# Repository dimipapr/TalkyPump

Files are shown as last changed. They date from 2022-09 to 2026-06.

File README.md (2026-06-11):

# TalkyPump

TalkyPump firmware project.

The legacy v1 firmware is preserved under `archive/` as a behavioral reference.

Active same-hardware v2 development happens under `firmware/`.

Target hardware:

- ATmega168
- SIM800L
- existing relay control hardware
- existing relay state input
- existing alarm inputs
- existing mains/zero-cross input
- existing indication LED

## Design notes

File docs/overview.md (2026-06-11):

# Product overview

## What TalkyPump is

TalkyPump is a GSM remote monitoring and control tool for existing seal-in irrigation pump installations.

It connects to the existing relay control circuit and works alongside the local manual controls. It does not replace the pump control panel, bypass interlocks, or replace overload and electrical protection devices.

TalkyPump acts as an additional authorized remote operator for the existing installation.

## Problem addressed

Irrigation pump installations are often unattended and physically distant from the farmer.

This creates two practical problems.

### Unplanned events

Failures and state changes can happen at any time. Examples include mains power loss, power returning, or the pump stopping because the existing control/protection circuit has dropped out.

Without remote monitoring, there is a blind interval between the event and the farmer becoming aware of it. During that time, irrigation may be interrupted, the exact time of failure may be unknown, and the farmer may need repeated visits just to check whether the mains power has recovered.

### Simple control actions

Some visits are not caused by faults. They are only needed because someone has to press a local start or stop button at the installation.

## Product purpose

TalkyPump reduces the cost of distance from unattended irrigation pump installations.

It does this in two ways:

- **monitoring**: reducing the time between an unplanned event and farmer awareness
- **control**: avoiding field visits for simple authorized start/stop actions

## High-level functionality

TalkyPump provides four main product functions:

### Pump monitoring

TalkyPump monitors the pump/control-circuit state so the farmer can know whether the installation appears to be running or stopped.

### Mains monitoring

TalkyPump monitors mains-power availability through the existing installation signal.

When mains loss or recovery is detected, the event should be reportable to the farmer.

### Remote pump control

TalkyPump allows authorized users to send remote start and stop commands to the existing relay control circuit.

These commands act in parallel with the local manual controls and do not replace the existing control or protection system.

### User access control

TalkyPump restricts control actions to authorized users.

Unauthorized callers or message senders are not be able to start or stop the pump.

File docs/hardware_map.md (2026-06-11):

# Hardware map

Status: schematic checked, real-device notes included.

## MCU

| Item | Value |
|---|---|
| MCU | ATmega168PA |
| Supply | 5 V |
| Clock | internal 8 MHz |
| UART | USART0 used for SIM800 |
| Programming | ISP header |

## SIM800 modem

The SIM800 modem is connected to the ATmega168 hardware UART.

| Purpose | MCU pin | Board net | Notes |
|---|---:|---|---|
| MCU receives data from modem | PD0 / RXD | `GTx` | SIM800 TX → MCU RX |
| MCU sends data to modem | PD1 / TXD | `GRx` | MCU TX → SIM800 RX |
| Modem power control | PD5 | `GSMPWR` | controls modem power-key circuit |

Firmware settings:

- UART peripheral: USART0
- No second UART is available
- Tested baud rate: 38400, supports autobaud

## Outputs

| Function | MCU pin / net | Active state | Notes |
|---|---|---|---|
| Relay stop pulse | PD2 / `RelStop` | high | drives relay driver, legacy pulse approx. 500 ms |
| Relay start pulse | PD3 / `RelStart` | high | drives relay driver, legacy pulse approx. 200 ms |
| GSM power key | PD5 / `GSMPWR` | high | active-high firmware signal; pulls SIM800 PWRKEY low |
| Status LED | PC4 / `ADC2` terminal | high | external/manual LED connected on real devices |

## Inputs

| Function | MCU pin / net | Open state | Closed state | Notes |
|---|---|---|---|---|
| Relay state feedback | PC0 / `RelSensor` | high | low | external pull-up; contact/input closure pulls low |
| Alarm 1 | PC1 / `Alarm1` | high | low | external pull-up; contact/input closure pulls low |
| Alarm 2 | PC2 / `Alarm2` | high | low | external pull-up; contact/input closure pulls low |
| Mains / zero-cross activity | PD4 / `OptOut` | - | - | pin-change activity indicates mains voltage threshold transition |

## Auxiliary terminals

| Function | MCU pin / net | Open state | Closed state | Notes |
|---|---|---|---|---|
| ADC/input 1 | PC3 / `ADC1` | high | low | available terminal, v2 use TBD |

## Firmware constraints

- Relay outputs must initialize inactive before any application logic runs.
- Relay start/stop pulses must never occur accidentally during boot.
- USART0 is dedicated to the SIM800 modem.
- No second hardware UART is available for logging.
- Status/debug indication shall use the external LED on `ADC2` / PC4.
- Mains presence is detected from zero-cross activity on PD4.
- On confirmed mains loss, firmware shall persist the shutdown event before attempting GSM/SMS work.
- Optional GPRS diagnostics must not be required for pump control.

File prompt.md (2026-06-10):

Act as a conservative legacy embedded C maintenance reviewer.

Project:
Legacy v1 field firmware for an agricultural pump remote-control/monitoring device.

Hardware/context:
- MCU: ATmega168
- Modem: SIM800L
- Original development period: around 2020
- The same hardware is already deployed in the field
- Some deployed devices may be updated/reflashed
- Some users may need replacement devices using the same hardware design
- The firmware mostly worked in practice, but the code became hard to maintain
- Some field failures/duds were hard to diagnose

Goal:
Stabilize and maintain the existing v1 firmware for the current ATmega168 + SIM800L field devices.

The goal is to make the firmware buildable, understandable, and safe enough to maintain for existing users and same-hardware replacement devices.

This is a maintenance rescue project, not a rewrite.

Working rules:
- Do not redesign the firmware.
- Do not add new features unless explicitly requested.
- Preserve existing field-proven behavior unless a bug is obvious and discussed.
- Assume existing deployed hardware remains the hardware target.
- Prefer small, safe, reviewable changes.
- Be conservative about behavior changes.
- Separate current facts, inferred behavior, risks, likely bugs, and proposed changes.
- Mark unknowns clearly instead of guessing.
- Assume regressions are dangerous.
- Optimize for build reproducibility, flash/RAM reduction, obvious bug fixes, and maintainability.
- Avoid clever abstractions.
- Avoid turning freed flash into feature budget.
- Treat freed flash as safety margin.
- Keep the firmware understandable enough to service existing users.

Advisory style:
- Do not be overly assertive when the correct direction is uncertain.
- Treat proposed changes as options unless the evidence clearly supports them.
- Distinguish between facts, inferences, recommendations, and open questions.
- Push back when a proposed change increases regression risk, expands scope, hides uncertainty, or conflicts with the maintenance goal.
- Say when something is too risky to change without more information.
- Prefer “possible,” “likely,” “I would consider,” and “needs confirmation” language where appropriate.
- Do not turn exploratory ideas into plans unless explicitly asked.
- If the safest next step is to pause, inspect, or ask for a missing file, say so.

Source-of-truth rules:
- Do not assume implementation details.
- Do not rely on memory from previous chats.
- Use only the documents, code, repository structure, and user input provided in this chat.
- Treat provided files and user corrections as the source of truth.
- If something is missing, unclear, or contradictory, say so directly.
- Use the repository structure only to understand layout and identify relevant files.
- Do not infer behavior from filenames alone.
- Ask directly for the smallest additional file, setting, or clarification needed.
- If code and user-described behavior disagree, call out the mismatch instead of silently resolving it.

Important scope:
- First priority is making the project build from Linux without AVR Studio.
- Second priority is documenting current behavior from the code.
- Third priority is safe cleanup and obvious bug fixes.
- Removing unused features is acceptable if confirmed, especially features no one uses.
- Pressure sensor support, new product behavior, hardware redesign, or major rewrites are out of scope for the rescue branch unless explicitly requested later.

Initial tasks:
1. Read the provided project structure and files.
2. Build a behavior map from the provided code.
3. Identify the current feature set.
4. Identify EEPROM layout and persistent state.
5. Identify global flags and state meanings.
6. Identify SMS commands and call/ring behavior.
7. Identify timer, watchdog, power-loss, and GSM recovery behavior.
8. Identify obvious bugs and high-risk areas.
9. Identify flash/RAM reduction opportunities.
10. Propose a minimal Linux-native `avr-gcc` / `avrdude` build path.
11. Propose a safe cleanup sequence with small bisectable commits.
12. Ask for any extra files, settings, or hardware details needed for the next step.

Preferred output style:
- Be direct and practical.
- Do not over-assert when behavior is inferred.
- Use sections:
  - Current facts
  - Inferred behavior
  - Risks
  - Likely bugs
  - Safe cleanup candidates
  - Files/settings needed next
  - Suggested first commits
- Do not produce large rewrites unless asked.
- When proposing code changes, keep them minimal and explain the regression risk.

Git workflow expectations:
- One logical change per commit.
- Preserve the original source as an import/baseline.
- Keep generated `.hex` and size output for field candidates.
- Make changes easy to bisect.
- Avoid “cleanup everything” commits.
- Track which firmware candidate is flashed to which physical device when possible.

Repository structure:
[PASTE PROJECT TREE HERE]

Start by reading the project structure and provided files, then tell me:
- the current behavior map
- the risk map
- a first-pass bug list
- the smallest next action
- which file, setting, or clarification you need next

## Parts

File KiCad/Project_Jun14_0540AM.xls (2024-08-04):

 |  | MOUSER
 | PTELEPUMP
Schem Refference | Mouser No | Mfr. No | Manufacturer | Customer No | Description | RoHS | Lifecycle | Order Qty. | Price (EUR) | Ext.: (EUR)
 | 512-H11L1M | H11L1M | ON Semiconductor |  | Logic Output Opto-couplers Optocoupler LC Schmitt Trigger | RoHS Compliant |  | 1 | 0.819 | 0.819
 | 625-1N4005-E3/54 | 1N4005-E3/54 | Vishay |  | Rectifiers Vr/600V Io/1A | RoHS Compliant By Exemption |  | 2 | 0.135 | 0.27
 | 769-ALQ105 | ALQ105 | Panasonic |  | General Purpose Relays LQ Relay | RoHS Compliant By Exemption |  | 2 | 2.18 | 4.36
 | 625-1N4001-E3/73 | 1N4001-E3/73 | Vishay |  | Rectifiers Vr/50V Io/1A | RoHS Compliant By Exemption |  | 2 | 0.18 | 0.36
 | 512-BC33725TAR | BC33725TAR | ON Semiconductor |  | Bipolar Transistors - BJT NPN Si Transistor Epitaxial | RoHS Compliant |  | 2 | 0.225 | 0.45
 | 667-ECA-1CM221B | ECA-1CM221B | Panasonic |  | Aluminium Electrolytic Capacitors - Radial Leaded Al Lytic Cap 85C Radial M Series | RoHS Compliant |  | 1 | 0.216 | 0.216
 | 647-UVR2A0R1MDD1TA | UVR2A0R1MDD1TA | Nichicon |  | Aluminium Electrolytic Capacitors - Radial Leaded 0.1uF 20% 100V Miniature Sized | RoHS Compliant |  | 1 | 0.144 | 0.144
 | 506-FSM2JRT | FSM2JRT | TE Connectivity |  | Tactile Switches TACTILE SWITCH 12VDC 1.57N | RoHS Compliant |  | 1 | 0.108 | 0.108
 | 709-IRM20-5 | IRM-20-5 | MEAN WELL |  | AC/DC Power Modules 5V 4A 20W 85-264Vin Encap PS | RoHS Compliant |  | 1 | 9.41 | 9.41
 | 594-MBA0204BC3002FCT | MBA0204BC3002FCT00 | Vishay |  | Metal Film Resistors - Through Hole 1/4W 30K ohms 1% | RoHS Compliant |  | 6 | 0.09 | 0.54
 | 594-MBA02040C1001FCT | MBA02040C1001FCT00 | Vishay |  | Metal Film Resistors - Through Hole .4watt 1Kohms 1% | RoHS Compliant |  | 4 | 0.126 | 0.504
 | 652-RLB0608-100KL | RLB0608-100KL | Bourns |  | Fixed Inductors 10uH 10% 550mA | RoHS Compliant |  | 1 | 0.225 | 0.225
 | 660-MOS1CT528R683J | MOS1CT528R683J | KOA Speer |  | Metal Oxide Resistors 68K ohm 5% 1W | RoHS Compliant | New Product | 1 | 0.101 | 0.101
 | 531-PT10V-20K-S | PT10LV10-203A2020-S | Amphenol |  | Trimmer Resistors - Through Hole 20Kohms 10mm Rnd Top adj Steel Lead | RoHS Compliant |  | 1 | 0.486 | 0.486
 |  |  |  |  |  |  |  |  |  | 0
 |  |  |  |  |  |  |  |  |  | 0
 |  | CABLEWORKS |  |  |  |  |  |  |  | 0
 | KF301-3P |  | OEM |  | 5.08mm 3 Pin Screw Terminal Connector |  |  | 3 | 0.43 | 1.29
 | KF301-2P |  | OEM |  | 5.08mm 2 Pin Screw Terminal Connector |  |  | 1 | 0.25 | 0.25
 | 1116174 |  | OEM |  | 40-Pin Female Single Row 2.54mm Pin Header Strip |  |  | 1 | 0.3 | 0.3
 | 1116175 |  | OEM |  | 40-Pin Male Single Row 2.54mm Pin Header Strip |  |  | 1 | 0.3 | 0.3
 |  |  |  |  |  |  |  |  |  | 0
 |  |  |  |  |  |  |  |  |  | 0
 |  |  |  |  |  |  |  |  |  | 0
 |  |  |  |  |  |  |  |  |  | 0
 |  |  |  |  |  |  |  |  |  | 0
 |  |  |  |  |  |  |  |  |  | 0
 |  |  |  |  |  |  |  |  |  | 0
 |  |  |  |  |  |  |  |  |  | 0
 |  |  |  |  |  |  |  |  |  | 0
 |  |  |  |  |  |  |  |  |  | 0
 |  |  |  |  |  |  |  |  | Sum | 17.993

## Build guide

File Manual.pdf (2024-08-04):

- ΠΡΩΤΗ ΕΚΚΙΝΗΣΗ
Με τη σύνδεση της τροφοδοσίας της συσκευής το ενδεικτικό LED παραμένει αναμένο για 15-30 δευτερόλεπτα. Μόλις αρχίσει να αναβοσβήνει σταθερά (1 φορά το δευτερόλεπτο περίπου), η συσκευή έχει συνδεθεί στο δίκτυο και μπορεί να δεχτεί κλήσεις.
- ΚΑΤΑΧΩΡΗΣΗ ΔΙΑΧΕΙΡΙΣΤΗ
Η συσκευή αρχικά πρέπει να είναι συνδεμένη στο δίκτυο (LED αναβοσβήνει). Πραγματοποιώντας μια κλήση στη συσκευή, μετά από 6-7 χτηπήματα, η συσκευή θα την απορρίψει και θα καταχωρήσει τον αριθμό του καλούντος ως διαχειριστή (το LED ανάβει για πολύ λίγο 1 φορά στα 4 δευτερόλεπτα). Πλέον θα δέχεται κλήσεις μόνο από το διαχειριστή και θα απορρίπτει τις υπόλοιπες.
- ΔΙΑΧΕΙΡΗΣΗ ΣΥΣΚΕΥΗΣ ΜΕΣΩ SMS
Η συσκευή δέχεται τις ακόλουθες εντολές μέσω SMS μόνο από το τηλέφωνο του καταχωρημένου διαχειριστή. Το SMS πρέπει να ξεκινάει με τον τετραψήφιο κωδικό ακολουθούμενο από την εντολή και τέλος τα δεδομένα που διαφέρουν ανάλογα με την εντολή. Το SMS δεν πρέπει να περιέχει κενά και τα γράμματα πρέπει να είναι πεζά και λατινικά. Μετά από κάθε εντολή η συσκευή απαντάει σχετικά με την εκτέλεση της εντολής με σχετικό SMS.
Μορφή εντολής: | [Κωδικός][Εντολή][Δεδομένα]
[Κωδικός]: | τετραψήφιος αριθμητικός κωδικός με αρχική τιμή 0000. Μπορεί να αλλαχθεί μέσω
της εντολής chp.
[Δεδομένα]: | δεκαψήφιος τηλεφωνικός αριθμός, τετραψήφιος κωδικός ή τίποτα ανάλογα
με την εντολή.

Εντολές:

### 1. Προσθήκη χρήστη

Εκτός του διαχειριστή μπορούν να προστεθούν έως και 5 ακόμη αριθμοί χρηστών. Η συσκευή δεν δέχεται αριθμούς σταθερού τηλεφώνου.

Μορφή εντολής: Κωδικός+Αριθμός

π.χ. Για προσθήκη του αριθμού 6910000000 σε συσκευή με κωδικό 0000 πρέπει ο διαχειριστής να στείλει το ακόλουθο SMS:
0000+6910000000

Απαντήσεις:
ΑΠΑΝΤΗΣΗ | ΠΕΡΙΓΡΑΦΗ
PROSTHIKI: 6910000000 OK | Επιτυχής προσθήκη αριθμού 6910000000
MNHMH PLHRHS | Η συσκευή έχει το μέγιστο αριθμό χρηστών(6). Αφαιρέστε χρήστες για να ελευθερώσετε χώρο.
6910000000:HDH APOTHIKEUMENOS | Ο αριθμός είναι είδη αποθηκευμένος
ARITHMOS MH APODEKTOS | Μη αποδεκτός αριθμός. Η συσκευή δέχεται μόνο δεκαψήφιους αριθμούς κινητού τηλεφώνου.

### 2. Αφαίρεση χρήστη

Μορφή εντολής: Κωδικός-Αριθμός

π.χ. Για αφαίρεση του αριθμού 6910000000 σε συσκευή με κωδικό 0000 πρέπει ο διαχειριστής να στείλει το ακόλουθο SMS:
0000-6910000000

Απαντήσεις:
ΑΠΑΝΤΗΣΗ | ΠΕΡΙΓΡΑΦΗ
AFAIRESI: 6910000000 OK | Επιτυχής αφαίρεση αριθμού 6910000000
AFAIRESI: 6910000000 DE VRETHIKE | Ο αριθμός δεν είναι αποθηκευμένος στη συσκευή

### 3. Αναφορά ενεργών χρηστών

Η συσκευή στέλνει τους αριθμούς που έχουν πρόσβαση εκτος του διαχειριστη.

Μορφή εντολής: Κωδικός?

π.χ. 0000?

ΑΠΑΝΤΗΣΗ | ΠΕΡΙΓΡΑΦΗ
HRISTES: 6910000000 6910000001 | Οι αριθμοί που βρίσκονται στη λίστα έχουν πρόσβαση στη συσκευή

### 4. Αλλαγή κωδικού

Μορφή εντολής: ΠαλιόςΚωδικόςchpΝέοςΚωδικός

π.χ. 0000Chp1234

ΑΠΑΝΤΗΣΗ | ΠΕΡΙΓΡΑΦΗ
1234 | Σε περίπτωση επιτυχής αλλαγής του κωδικού η συσκευή στέλνει το νέο κωδικό στον διαχειριστή

### 5. Επανεκκίνηση Συσκευής

Μορφή εντολής: Κωδικόςrst

π.χ. 0000rst

### 6. Επαναφορά Αρχικών Ρυθμίσεων

Η εντολή επαναφέρει τη συσκευή στην αρχική της κατάσταση σβήνοντας τους αριθμούς χρηστών και διαχειριστή.

Μορφή εντολής: Κωδικόςdef

π.χ. 0000def

ΑΠΑΝΤΗΣΗ | ΠΕΡΙΓΡΑΦΗ
EPANAFORA | -

**Σε περίπτωση που δεν είναι δυνατή η επαναφορά της συσκευής με την παραπάνω εντολή μέσω του διαχειριστή, η επαναφορά μπορεί να πραγματοποιηθεί αποστέλλοντας μέσω SMS από οποιοδήποτε τηλέφωνο, χωρίς κωδικό και κενά, του δεκαεξαψήφιου αριθμού που βρίσκεται στο τέλος του παρόντος κειμένου.

- ΣΥΓΚΕΝΤΡΩΤΙΚΟΣ ΠΙΝΑΚΑΣ ΕΝΤΟΛΩΝ
| ΠΕΡΙΓΡΑΦΗ | ΣΥΜΒΟΛΟ | ΔΕΔΟΜΕΝΑ | ΠΑΡΑΔΕΙΓΜΑ
1 | Προσθήκη χρήστη | + | Αριθμός νέου χρήστη | 0000+6910000000
2 | Αφαίρεση χρήστη | - | Αριθμός χρήστη | 0000-6910000000
3 | Αναφορά ενεργών χρηστών | ? | - | 0000?
4 | Αλλαγή κωδικού | chp | Νέος κωδικός | 0000chp1234
5 | Επανεκκίνηση | rst | - | 0000rst
6 | Επαναφορά | def | - | 0000def
- ΧΡΗΣΗ ΤΗΣ ΣΥΣΚΕΥΗΣ
Εφόσον υπάρχει καταχωρημένος διαχειριστής στο σύστημα και η συσκευή βρίσκεται σε κατάσταση λειτουργίας (LED ανάβει για λίγο μία φορά κάθε 4 ''), οποιοσδήποτε καταχωρημένος αριθμός μπορεί να εκτελέσει τις ακόλουθες λειτουργίες πραγματοποιώντας τηλεφωνική κλήση προς τη συσκευή:

### 1. Άνοιγμα-Κλείσιμο Ρελέ

Μετά από 2 χτυπήματα η συσκευή απορρίπτει την κλήση και αλλάζει την κατάσταση του ρελέ από ανοικτό σε κλειστό ή το αντίστροφο.

### 2. Ερώτηση Κατάστασης

Μετά το πρώτο χτύπημα και πριν η συσκευή απορρίψει την κλήση τερματίστε την κλήση. Η συσκευή θα στείλει SMS στον χρήστη που έκανε την κλήση με την κατάσταση του συστήματος.

- ΣΥΣΤΗΜΑ ΕΙΔΟΠΟΙΗΣΕΩΝ
Η συσκευή παρακολουθεί και ενημερώνει μέσω SMS για κάθε αλλαγή κατάστασης του ρελέ, της τροφοδοσίας του δικτύου ενέργειας, καθώς και σε περίπτωση παραβίασης των επαφών συναγερμού. Τα ενημερωτικά SMS αποστέλλονται στο χρήστη που εκτέλεσε την τελευταία λειτουργία στη συσκευή (πραγματοποίησε τελευταίος κλήση προς τη συσκευή).

### 1. ΚΑΤΑΣΤΑΣΗ ΡΕΛΕ

Μετά από κάθε αλλαγή κατάστασης του ρελέ αποστέλλεται ενημερωτικό SMS με την τρέχουσα κατάστασή του.
SMS | ΠΕΡΙΓΡΑΦΗ
REL ON | Το ρελέ βρίσκεται σε κατάσταση λειτουργίας
REL OFF | Το ρελέ βρίσκεται εκτός λειτουργίας

### 2. ΚΑΤΑΣΤΑΣΗ ΔΙΚΤΥΟΥ ΡΕΥΜΑΤΟΣ

Σε περίπτωση διακοπής της παροχής ρεύματος η συσκευή αποστέλλει ενημερωτικό SMS.
SMS | ΠΕΡΙΓΡΑΦΗ
DEH OFF | Διακοπή του δικτύου ρεύματος

### 3. ΚΑΤΑΣΤΑΣΗ ΣΥΝΑΓΕΡΜΩΝ

SMS | ΠΕΡΙΓΡΑΦΗ
PARAVIASI 1 | Παραβίαση του συναγερμού 1
PARAVIASI 2 | Παραβίαση του συναγερμού 2
Μετά την παραβίαση των επαφών συναγερμού, για την επαναλειτουργία τους, η συσκευή πρέπει να επανεκκινηθεί, μέσω SMS και της εντολής rst ή με διακοπή και επαναφορά της τροφοδοσίας ρεύματος.

### 4. ΕΚΚΙΝΗΣΗ ΣΥΣΚΕΥΗΣ/ ΕΠΑΝΑΦΟΡΑ ΡΕΥΜΑΤΟΣ

Κατά την εκκίνηση της συσκευής ή μετά την επαναφορά του δικτύου ρεύματος αποστέλλεται ενημερωτικό SMS με την τρέχουσα κατάσταση του ρελέ καθώς και των επαφών συναγερμού.
SMS | ΠΕΡΙΓΡΑΦΗ
REL OFF AL1 OK AL2 OK | Η συσκευή έχει εκκινήσει, το ρελέ είναι εκτός λειτουργίας και οι συναγερμοί δεν έχουν παραβιαστεί.

### 5. ΕΡΩΤΗΣΗ ΚΑΤΑΣΤΑΣΗΣ ΣΥΣΤΗΜΑΤΟΣ

Ο κάθε χρήστης μπορεί να ζητήσει την κατάσταση συστήματος πραγματοποιώντας κλήση προς την συσκευή και τερματίζοντάς την μετά το πρώτο χτύπημα.

SMS | ΠΕΡΙΓΡΑΦΗ
REL ΟΝ AL1 OK AL2 OK | Το ρελέ είναι σε κατάσταση λειτουργίας και οι συναγερμοί δεν έχουν παραβιαστεί.

PN01SN01FW1V2.2
0576811764143827

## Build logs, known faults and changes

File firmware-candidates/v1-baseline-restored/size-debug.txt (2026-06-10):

   text	   data	    bss	    dec	    hex	filename
   6636	    538	    231	   7405	   1ced	artifacts/v1-baseline-restored/Debug/TalkyPump.elf

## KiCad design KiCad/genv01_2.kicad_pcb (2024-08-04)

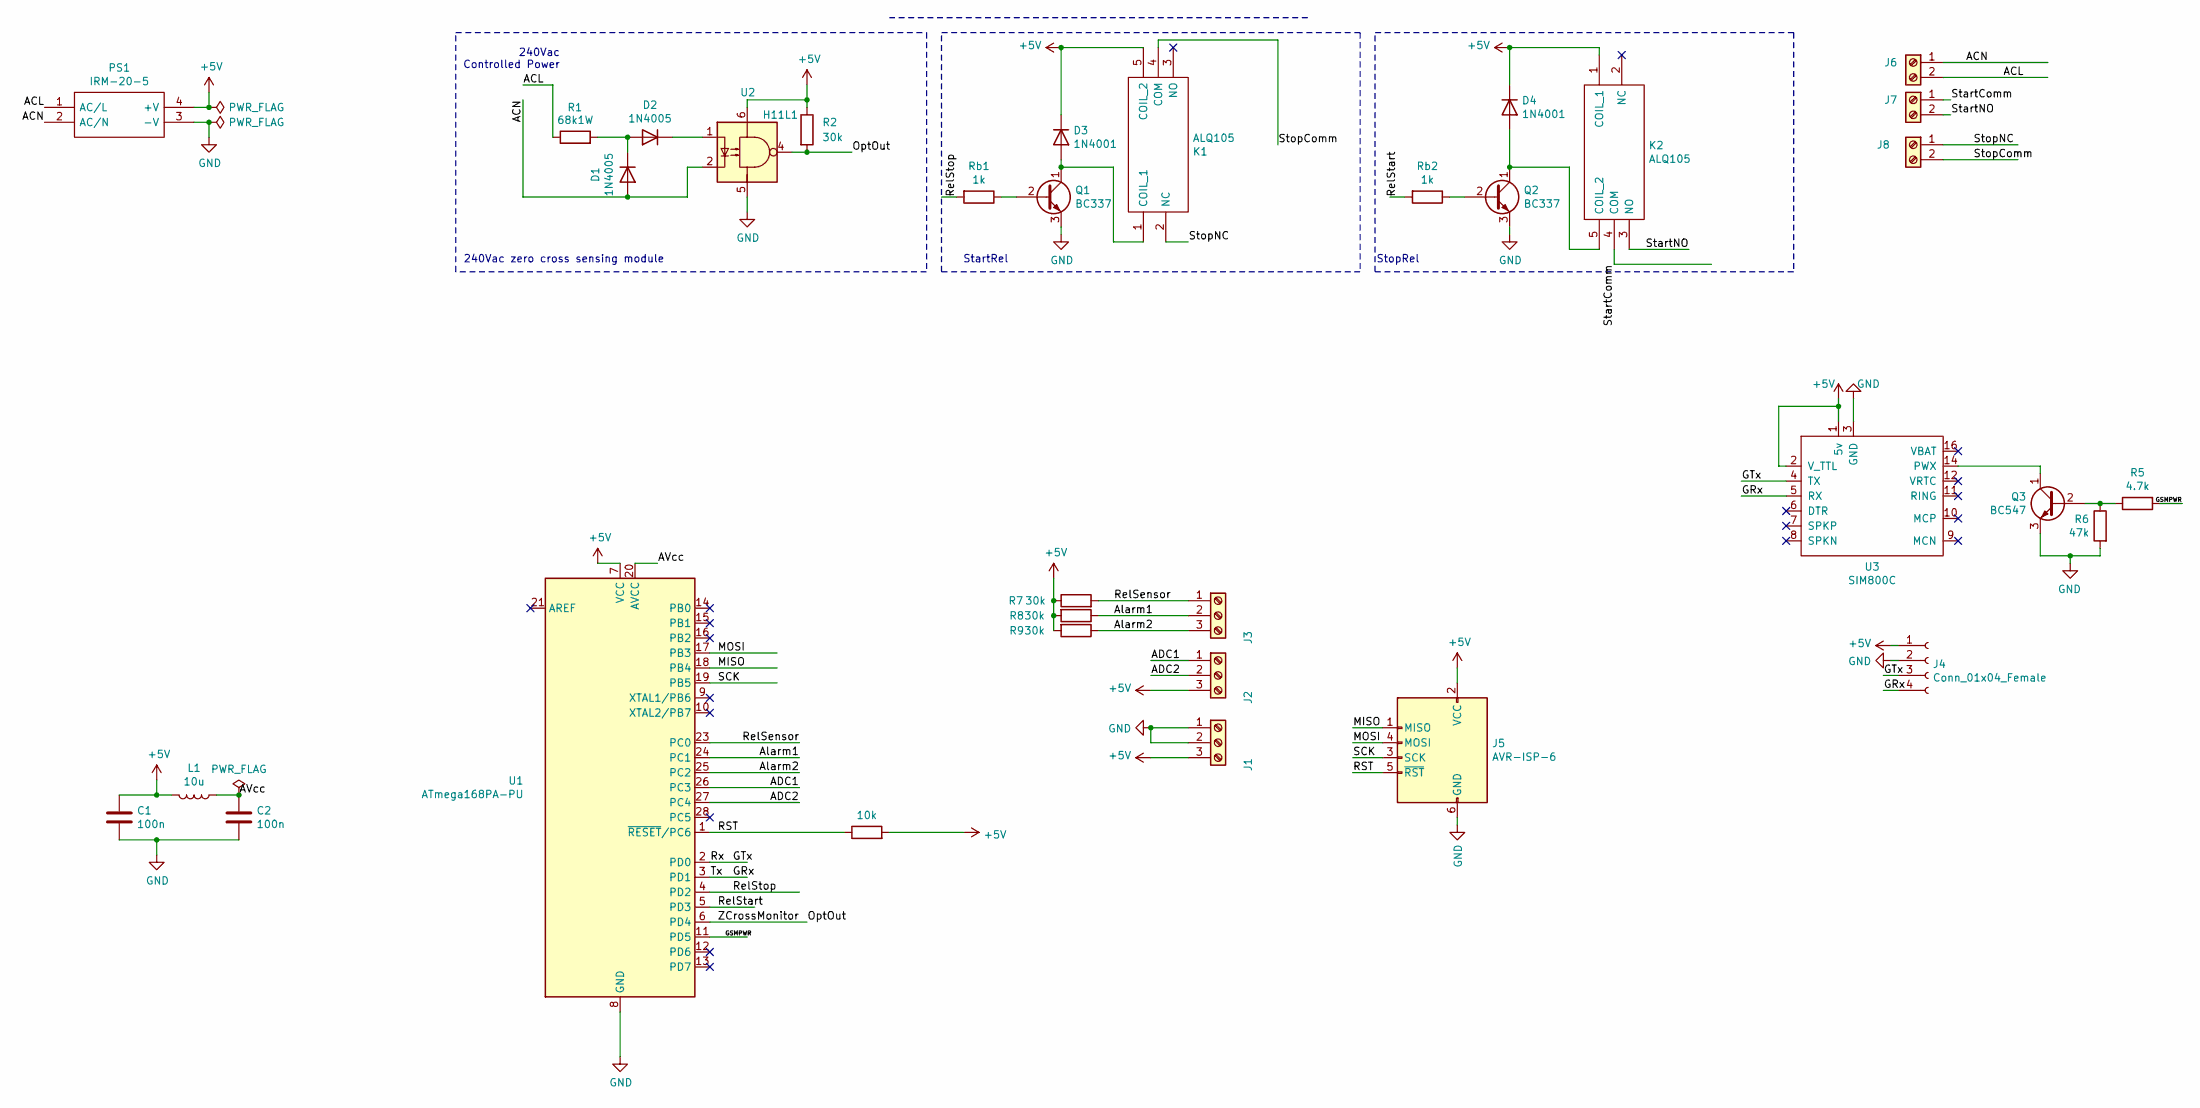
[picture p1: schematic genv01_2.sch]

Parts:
C1, C2: 100n; K104K10X7RF5UL2
D1, D2: 1N4005; D_A-405_P7.62mm_Horizontal
D3, D4: 1N4001; D_A-405_P7.62mm_Horizontal
J1, J2, J3: Screw_Terminal_1x3; Screw_terminal_1x3_5.08mm
J4: Conn_01x04_Female; PinHeader_1x04_P2.54mm_Vertical
J5: AVR-ISP-6; PinHeader_2x03_P2.54mm_Vertical
J6, J7, J8: Screw_Terminal_01x02; Screw_terminal_1x2_5.08mm
K1, K2: ALQ105; Manufacturer_Part_Number ALQ105; Mouser Part Number 769-ALQ105
L1: 10u; L_Radial_5mm_2mm
PS1: IRM-20-5; IRM2024; Manufacturer_Part_Number IRM-20-5; Mouser Part Number 709-IRM20-5
Q1, Q2: BC337; TO-92L_Wide
Q3: BC547; TO-92L_Wide
R1: 68k1W; R_Axial_DIN0309_L9.0mm_D3.2mm_P12.70mm_Horizontal
R2, R7, R8, R9: 30k; R_Axial_DIN0204_L3.6mm_D1.6mm_P5.08mm_Horizontal
R3: 10k; R_Axial_DIN0204_L3.6mm_D1.6mm_P5.08mm_Horizontal
R5: 4.7k; R_Axial_DIN0207_L6.3mm_D2.5mm_P7.62mm_Horizontal
R6: 47k; R_Axial_DIN0207_L6.3mm_D2.5mm_P7.62mm_Horizontal
Rb1, Rb2: 1k; R_Axial_DIN0204_L3.6mm_D1.6mm_P5.08mm_Horizontal
U1: ATmega168PA-PU; DIP-28_W7.62mm
U2: H11L1; DIP-6_W7.62mm_Socket
U3: SIM800C

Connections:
+5V: C1.1, D3.1 (K), D4.1 (K), J1.3, J2.3, J4.1, J5.2 (VCC), K1.5 (COIL_2), K2.1 (COIL_1), L1.2, PS1.4 (+V), R2.1, R3.2, R7.1, R8.2, R9.2, U1.7 (VCC), U2.6, U3.1 (5v), U3.2 (V_TTL)
/ACL: J6.2, PS1.1 (AC/L), R1.1
/ACN: D1.2 (A), J6.1, PS1.2 (AC/N), U2.2
/ADC1: J2.1, U1.26 (PC3)
/ADC2: J2.2, U1.27 (PC4)
/AVcc: C2.1, L1.1, U1.20 (AVCC)
/Alarm1: J3.2, R8.1, U1.24 (PC1)
/Alarm2: J3.3, R9.1, U1.25 (PC2)
/GRx: J4.4, U1.3 (PD1), U3.5 (RX)
/GSMPWR: R5.2, U1.11 (PD5)
/GTx: J4.3, U1.2 (PD0), U3.4 (TX)
/MISO: J5.1 (MISO), U1.18 (PB4)
/MOSI: J5.4 (MOSI), U1.17 (PB3)
/OptOut: R2.2, U1.6 (PD4), U2.4
/RST: J5.5 (~RST), R3.1, U1.1 (~RESET~/PC6)
/RelSensor: J3.1, R7.2, U1.23 (PC0)
/RelStart: Rb2.2, U1.5 (PD3)
/RelStop: Rb1.2, U1.4 (PD2)
/SCK: J5.3 (SCK), U1.19 (PB5)
/StartComm: J7.1, K2.4 (COM)
/StartNO: J7.2, K2.3 (NO)
/StopComm: J8.2, K1.4 (COM)
/StopNC: J8.1, K1.2 (NC)
GND: C1.2, C2.2, J1.1, J1.2, J4.2, J5.6 (GND), PS1.3 (-V), Q1.3 (E), Q2.3 (E), Q3.3 (E), R6.2, U1.8 (GND), U1.22 (GND), U2.5, U3.3 (GND), U3.13 (GND), U3.15 (GND)
unnamed: D1.1 (K), D2.2 (A), R1.2
unnamed: D2.1 (K), U2.1
unnamed: D3.2 (A), K1.1 (COIL_1), Q1.1 (C)
unnamed: D4.2 (A), K2.5 (COIL_2), Q2.1 (C)
unnamed: Q1.2 (B), Rb1.1
unnamed: Q2.2 (B), Rb2.1
unnamed: Q3.1 (C), U3.14 (PWX)
unnamed: Q3.2 (B), R5.1, R6.1

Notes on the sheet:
StartRel
240Vac Controlled Power
240Vac zero cross sensing module
StopRel

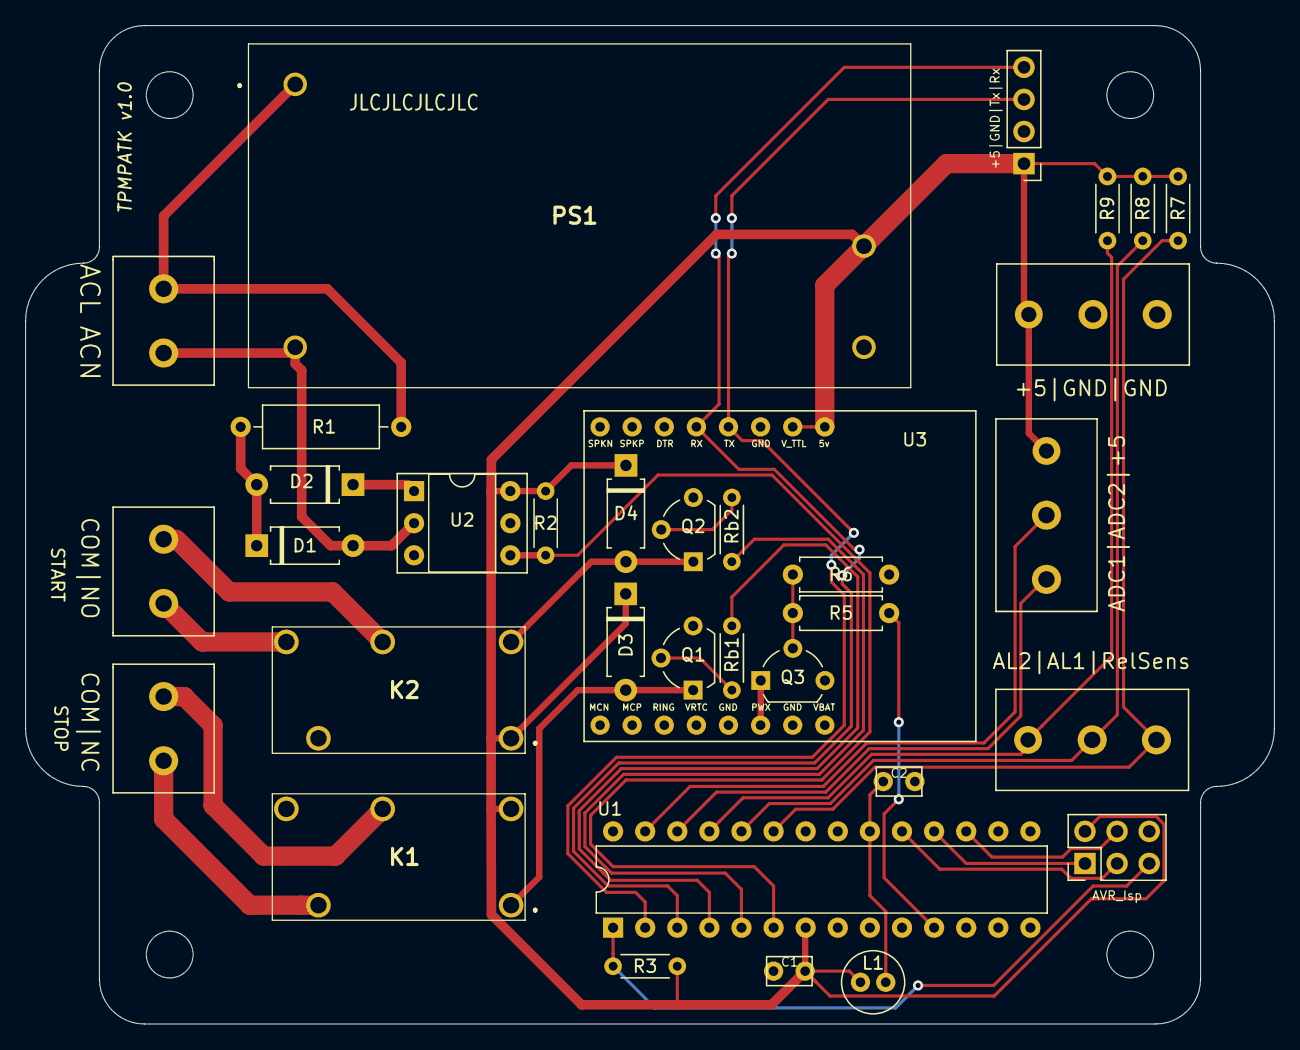
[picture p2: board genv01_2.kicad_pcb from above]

Board: 2 copper layers, 98.8 x 79.0 mm, 34 parts (0 on the bottom side), 32 nets.

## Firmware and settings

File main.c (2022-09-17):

/*
 * main.c
 *
 * Created: 22/7/2020 23:04:42
 *  Author: Jims
 */ 
#include "config.h"
#include "bitOperations.h"
#include "usart.h"
#include "gsm.h"

#include <avr/io.h>
#include <avr/wdt.h>
#include <avr/interrupt.h>
#include <string.h>
#include <avr/eeprom.h>
#include <stdlib.h>
#include <avr/pgmspace.h>






void init(void);
void IO_init(void);
void forceReset(uint8_t errCode);
void parseReceivedCommand(void);
void parseTxt(void);
uint8_t GSM_command_response(char *cmd, char *resp, uint8_t timeout/*(1-255* 0.1 seconds)*/,uint8_t repetitions); 
uint8_t setExpectedResponse(char *resp);
uint8_t GSM_init(void);
uint8_t GSM_Config(void);
uint8_t EEPROM_isValid(void);
uint8_t EEPROM_init(void);
void EEPROM_reset(void);
void EEPROM_update(void);
void EEPROM_validate(void);
uint8_t isValidNumber(char* number);
uint8_t isAdmin(char* number);
uint8_t isRegistered(char* number);
void startRelay(void);
void stopRelay(void);
void SMS_start(char* number);
void SMS_end(void);
uint8_t addControllingNumber(char* number);
uint8_t removeControllingNumber(char* number);
void stateReport();

volatile uint8_t mainF1 = MAINF1_INITIAL;
volatile uint8_t mainF2 = MAINF2_INITIAL;
volatile uint8_t mainF3 = MAINF3_INITIAL;
volatile uint8_t mainFP1 = MAINFP1_INITIAL;

char expectedResponse[EXPECTED_RESPONSE_SIZE];

uint8_t responseTimer,responseTimeout;

//indication LED
volatile uint8_t indLEDOnTime = 255; //0 - 255 = 0-8,4sec
volatile uint8_t indLEDCycleTime = 254;//0-255 = 0-8,4sec

volatile uint8_t tim0OvfIndTick;
volatile uint8_t tim0Ovf1;
volatile uint8_t tim0Ovf_1;
volatile uint8_t secCounter;
volatile uint8_t crossings;
volatile uint8_t tim0OvfSMSTick;

volatile uint8_t tim1OvfTick; 

uint8_t EEMEM EEValidationByte;
uint8_t EEMEM EEadminNo[10];
uint8_t EEMEM EEControlNums[50];
uint8_t EEMEM EEmainFP1;
uint8_t EEMEM EEValidationByte;
uint8_t EEMEM EEpsw[4];
uint8_t EEMEM EElastOpNumber[10];

uint8_t adminNo[10];
uint8_t controlNums[50];
uint8_t psw[4];
uint8_t callingNumber[10];
uint8_t lastOpNumber[10];
uint8_t rings;
uint8_t txt[32];


uint8_t state;






void disableWD(void) \
__attribute__((naked)) \
__attribute__((section(".init3")));
void disableWD(void)
{
	MCUSR = 0;
	wdt_disable();
}
int main(){
	state = INITIALISING;
	uint8_t tmp1=0,tmp2=0,tmp3=0,tmp4=0; //dont touch in isr
	uint8_t relChangeHits = 0,al1BreachHits = INPUTSENSITIVITY ,al2BreachHits = INPUTSENSITIVITY;
	
	init();
	indLEDCycleTime = 30;
	indLEDOnTime = 15;
	
	tim1OvfTick = 20; //~2.5mins
	
//wait for admin
	while(GET_BIT(mainFP1,ADMIN_FLAG)==0){
		wdt_reset();
		if(!GET_BIT(mainF2,POWER_STATE)){
			forceReset(ERR_POWER_DOWN);
		}
	}
	wdt_reset();
	tmp1 = INPUTSENSITIVITY;
	tmp2=0;
	tmp3=0;
	tmp4=0;
	do{
		if(!GET_BIT(PIN(P_RELAYSENSOR),B_RELAYSENSOR))tmp2++;
		if(GET_BIT(PIN(P_ALARM),B_ALARM1))tmp3++;
		if(GET_BIT(PIN(P_ALARM),B_ALARM2))tmp4++;
	}while(--tmp1>0);
	
	if((INPUTSENSITIVITY - tmp2)<(INPUTSENSITIVITY>>1) ){
		SET_BIT(mainFP1,RELAY_STATE);
		}else{
		CLEAR_BIT(mainFP1,RELAY_STATE);
	}
	if((INPUTSENSITIVITY - tmp3)<(INPUTSENSITIVITY>>1) ){
		SET_BIT(mainF2,ALARM1_STATE);
		}else{
		CLEAR_BIT(mainF2,ALARM1_STATE);
	}
	if((INPUTSENSITIVITY - tmp4)<(INPUTSENSITIVITY>>1) ){
		SET_BIT(mainF2,ALARM2_STATE);
		}else{
		CLEAR_BIT(mainF2,ALARM2_STATE);
	}
	SET_BIT(mainF1, EEPROM_UPDATE_PENDING);
	SET_BIT(mainF3,SMS_READY);
//main loop
	_delay_ms(1500);
	
	stateReport();
	indLEDOnTime = 1;
	indLEDCycleTime = 126;
	
	state = WORKING;
	while(1){
		wdt_reset();
		if(GET_BIT(mainF1,GSM_CALL_READY_DETECTED))
		{
			forceReset(ERR_GSM_REBOOT);
		}
	//eeprom Update
		if(GET_BIT(mainF1,EEPROM_UPDATE_PENDING)){
			EEPROM_update();
			sei();
		}
	//state report
		if(GET_BIT(mainF2,STATE_REPORT_PENDING)){
			stateReport();
		}
		if(!GET_BIT(mainF2,POWER_STATE)){ //anafora apo ISR_TIMER0
			cli();
			forceReset(ERR_POWER_DOWN);
		}
		if(GET_BIT(mainF3,NEW_SMS)){
			CLEAR_BIT(mainF3,NEW_SMS);
			_delay_ms(500);
			GSM_command(READ_SMS1);
			GSM_command_delimeter();
		}
		if(GET_BIT(mainF3,TXT_READY)){
			parseTxt();
			CLEAR_BIT(mainF3,NEW_SMS);
			CLEAR_BIT(mainF3,TXT_READY);
			CLEAR_BIT(mainF3,MASTER_SMS);
			SET_BIT(mainF3,SMS_READY);
			
		}
	//relay state read
		if(GET_BIT(PIN(P_RELAYSENSOR),B_RELAYSENSOR) == GET_BIT(mainFP1,RELAY_STATE)){
			relChangeHits ++;
			if(relChangeHits >= INPUTSENSITIVITY){
				_delay_ms(300);
				if(isValidNumber((char*)lastOpNumber)){
					SMS_start((char*)lastOpNumber);
					}else{
					SMS_start((char*)adminNo);
				}
				if(GET_BIT(PIN(P_RELAYSENSOR),B_RELAYSENSOR)){
					CLEAR_BIT(mainFP1,RELAY_STATE);
					USART_transmits("REL OFF");
				}else{
					SET_BIT(mainFP1,RELAY_STATE);
					USART_transmits("REL ON");
				}
				SMS_end();
				SET_BIT(mainF1,EEPROM_UPDATE_PENDING);
				relChangeHits = 0;
			}
		}else{
			relChangeHits = 0;
		}
	
	//alarms
		//alarm1
		if(GET_BIT(mainF2,ALARM1_FLAG))
		{
			if((PIN(P_ALARM)&(1<<B_ALARM1)) && !GET_BIT(mainF2,ALARM1_STATE) )
			{
				al1BreachHits--;
				if(al1BreachHits == 0)
				{
					if(isValidNumber((char*)lastOpNumber)){
						SMS_start((char*)lastOpNumber);
						}else{
						SMS_start((char*)adminNo);
					}
					USART_transmits("AL1 PARAVIASI");//anafora
					SMS_end();
					SET_BIT(mainF2,ALARM1_STATE);
				}
			}
			else
			{
				al1BreachHits = INPUTSENSITIVITY;
			}
		}
		if(GET_BIT(mainF2,ALARM2_FLAG) && !GET_BIT(mainF2,ALARM2_STATE) )
		{
			if(PIN(P_ALARM)&(1<<B_ALARM2))
			{
				al2BreachHits--;
				if(al2BreachHits == 0)
				{
					if(isValidNumber((char*)lastOpNumber)){
						SMS_start((char*)lastOpNumber);
						}else{
						SMS_start((char*)adminNo);
					}
					USART_transmits("AL2 PARAVIASI");//anafora
					SMS_end();
					SET_BIT(mainF2,ALARM2_STATE);
				}
			}else{
				al2BreachHits = INPUTSENSITIVITY;
			}
		}
	}
	return 0;
}
void init(){
	IO_init();
	USART_init(MYUBRR);
	//timer0 setup
	TCCR0B |= 0b00000101; // 1/1024 prescaler, ~33ms ovf @8MHz
	TIMSK0 |= (1<<TOIE0); //timer0 ovf interrupt enabled
	//timer1 setup
	TCCR1B |= 0b00000101; // 1/1024 prescaler, ~8,4sec ovf @8MHz
	TIMSK1 |= (1<<TOIE1);
	//zero cross monitor setup
	PCICR |= (1<<PCIE2);
	PCMSK2 |= (1<<PCINT20);
	sei(); //!!!!!!!!!!!!!!!!!!!!!!!!!!
	if(GSM_init()==0){
		//watchdog setup to reset early
		wdt_reset();
		WDTCSR |= (1<<WDCE)|(1<<WDE);
		WDTCSR =(1<<WDE)|(1<<WDP3)|(1<<WDP0);  //8s watchdog loop
		GSM_command(POWER_DOWN);
		GSM_command_delimeter();
		forceReset(ERR_GSM_INIT);
	}
	CLEAR_BIT(mainF1,GSM_CALL_READY_DETECTED);
	if(!EEPROM_init()){
		EEPROM_reset();
	}
	cli();
	//watchdog setup
	wdt_reset();
	WDTCSR |= (1<<WDCE)|(1<<WDE);
	WDTCSR = (1<<WDE)|(1<<WDP3)|(1<<WDP0);  //8s watchdog loop
	sei();
}
void IO_init(){
	DDR(P_RELAYCONTROL) |= (1<<B_RELAYSTART)|(1<<B_RELAYSTOP);
	DDR(P_GSMPOWER) |= (1<<B_GSMPOWER);
	PORT(P_GSMPOWER) |= (1<<B_GSMPOWER);
	DDR(P_INDICATION_LED) |= (1<<B_INDICATION_LED);
	PORT(P_INDICATION_LED) |= (1<<B_INDICATION_LED);
}
uint8_t EEPROM_init(){
	uint8_t tmp;
cli();																//interrupts disabled
	_delay_us(5);
	eeprom_busy_wait();
	tmp = eeprom_read_byte(&EEValidationByte);
	if(!EEPROM_isValid()){
		return 0;	
	}else
	{
		eeprom_busy_wait();
		eeprom_read_block((void*)psw,(const void*)EEpsw,4);
		mainFP1 = eeprom_read_byte(&EEmainFP1);
		if(GET_BIT(mainFP1,ADMIN_FLAG)==1)
		{
			eeprom_busy_wait();
			eeprom_read_block((void *)adminNo,(void *)EEadminNo,10);
			eeprom_busy_wait();
			eeprom_read_block((void *)lastOpNumber, (void *) EElastOpNumber,10);
			tmp = 5;
			do 
			{
				tmp--;
				if(GET_BIT(mainFP1,(CONTROLNO+tmp))){
					eeprom_busy_wait();
					eeprom_read_block((void*)(controlNums+tmp*10),(void *)(EEControlNums+tmp*10),10);
				}
			} while (tmp>0);	
		}
		return 1;
	}
}
void EEPROM_reset(){
cli();																//interrupts disabled
	_delay_us(5);
	memset((void*)adminNo,0x00,10);
	memset((void*)controlNums,0x00,50);
	memset((void*)lastOpNumber,0x00,10);
	memset((void*)psw,0x30,4); //password default "0000"
	mainFP1 = MAINFP1_INITIAL;
	EEPROM_update();
	EEPROM_validate();
	
}
void EEPROM_update(){
cli();																//interrupts disabled
	_delay_us(5);
	CLEAR_BIT(mainF1,EEPROM_UPDATE_PENDING);
	eeprom_busy_wait();
	eeprom_update_byte( &EEmainFP1, mainFP1);
	eeprom_busy_wait();
	//wdt_reset();
	eeprom_update_block((const void *)adminNo,(void *)EEadminNo,10);
	eeprom_busy_wait();
	eeprom_update_block((const void *)controlNums, (void *)EEControlNums, 50);
	eeprom_busy_wait();
	eeprom_update_block((const void *)lastOpNumber, (void *)EElastOpNumber,10);
	eeprom_busy_wait();
	eeprom_update_block((const void *)psw, (void *)EEpsw,4);
}
void EEPROM_validate(){
cli();																//interrupts disabled
	_delay_us(5);
	eeprom_busy_wait();
	eeprom_update_byte(&EEValidationByte, EEPROM_VALIDATION_BYTE);
}
uint8_t EEPROM_isValid(){
	uint8_t tmp;
cli();																//interrupts disabled
	_delay_us(5);
	eeprom_busy_wait();
	tmp = eeprom_read_byte(&EEValidationByte);
	return (tmp==EEPROM_VALIDATION_BYTE);
}
uint8_t GSM_init(){
	_delay_ms(5000);//bypass NORMAL POWER DOWN sent from GSM
		secCounter = 0;
		CLEAR_BIT(mainF1,GSM_COMMUNICATING);
		while(secCounter < 12){
			GSM_command("AT");
			GSM_command_delimeter();
			_delay_ms(200);
			if(GET_BIT(mainF1,GSM_COMMUNICATING)){
				secCounter = 0;
				while(!(!(secCounter<30)||GET_BIT(mainF1,GSM_CALL_READY_DETECTED)));//**
				if(GSM_Config()==0)return 0;
				break;
			}else if(secCounter == 10){
				GSM_powerToggle();
				secCounter = 0;
				while(!(!(secCounter<15)||GET_BIT(mainF1,GSM_CALL_READY_DETECTED)));
				if(GSM_Config()==0)return 0;
				break;
			}
		}
		CLEAR_BIT(mainF1,GSM_CALL_READY_DETECTED);
		return 1;
}
uint8_t GSM_Config(void){
	if(GSM_command_response("AT","OK",20,255) != RETVAL_SUCCESS)														return 0;
	if(GSM_command_response(DISABLE_ECHO,DISABLE_ECHO_RESPONSE,10,20)!= RETVAL_SUCCESS)									return 0;
	if(GSM_command_response(SMS_TXT_MODE,SMS_TXT_MODE_RESPONSE,10,20)!= RETVAL_SUCCESS)									return 0;
	if(GSM_command_response(ENABLE_CALL_RECOGNITION,ENABLE_CALL_RECOGNITION_RESPONSE,10,20)!= RETVAL_SUCCESS)			return 0;
	if(GSM_command_response(SET_FIXED_BAUD_38400,SET_FIXED_BAUD_38400_RESPONSE,10,20)!= RETVAL_SUCCESS)					return 0;
	if(GSM_command_response(ENABLE_SOFTWARE_FLOW_CONTROLL,ENABLE_SOFTWARE_FLOW_CONTROLL_RESPONSE,10,20)!= RETVAL_SUCCESS)return 0;
	if(GSM_command_response(SAVE_SETTINGS,SAVE_SETTINGS_RESPONSE,10,20)!= RETVAL_SUCCESS)								return 0;
	if(GSM_command_response(CALL_READY_CHECK,CALL_READY_RESPONSE,10,20)!= RETVAL_SUCCESS)								return 0;
	_delay_ms(2000);
	if(GSM_command_response(DELETE_ALL_SMS,DELETE_ALL_SMS_RESPONSE,10,40)!= RETVAL_SUCCESS)								return 0;
	return 1;
}
uint8_t GSM_command_response(char *cmd, char *resp, uint8_t timeout/*0.1sec, 25.5s max timeout @ timeout=0xFF*/,uint8_t repetitions)
{
	//NEEDS INTERRUPTS, SO DONT CALL FROM ISR, no?
	wdt_reset();
	if(repetitions>0){
		if(GET_BIT(mainF1,EXPECTING_RESPONSE))
		{
			return RETVAL_ALREADY_WAITING_FOR_RESPONSE;
		}
		while(repetitions > 0)
		{
			SET_BIT(mainF1, EXPECTING_RESPONSE);
			repetitions--;
			setExpectedResponse(resp);
			CLEAR_BIT(mainF1,EXPECTED_RESPONSE_RECEIVED);
			responseTimeout = timeout;
			responseTimer = 0;
			GSM_command(cmd);
			GSM_command_delimeter();
		
			while(!GET_BIT(mainF1,RESPONSE_TIMEOUT))
			{
				if(GET_BIT(mainF1,EXPECTED_RESPONSE_RECEIVED))
				{
					CLEAR_BIT(mainF1, EXPECTED_RESPONSE_RECEIVED);
					CLEAR_BIT(mainF1, EXPECTING_RESPONSE);
					return RETVAL_SUCCESS; //response received
				}
			}
			CLEAR_BIT(mainF1, EXPECTING_RESPONSE);
			CLEAR_BIT(mainF1,RESPONSE_TIMEOUT);
		}
		return RETVAL_TIMEOUT;// response timed out
	}else{
		return RETVAL_ZERO_REPETITIONS; // repetitions set to 0
	}
}
uint8_t setExpectedResponse(char *resp){
	if(strlen(resp)<EXPECTED_RESPONSE_SIZE){
		uint8_t i=0;
		while(resp[i]!='\0'){
			expectedResponse[i] = resp[i];
			i++;
		}
		expectedResponse[i] = resp[i];
		return 1;
	}
	return 0;
}
uint8_t addControllingNumber(char* number){
	uint8_t i;
	
	i=5;
	do 
	{
		i--;
		if(!GET_BIT(mainFP1,(CONTROLNO+i)))
		{//space found
			memcpy(controlNums+i*10,number,10);
			SET_BIT(mainFP1,(CONTROLNO+i));
			SET_BIT(mainF1,EEPROM_UPDATE_PENDING);
			return 1;
		}
	} while (i>0);
	return 0;
}
// called from usart.h
void parseReceivedCommand(){		//INTERRUPTS SHOULD BE DISABLED IN HERE!!!
	uint8_t i;
	SET_BIT(mainF1,GSM_COMMUNICATING);
	if( GET_BIT(mainF1,EXPECTING_RESPONSE) )
	{	
		if((strncmp(expectedResponse,receiveBuffer, strlen(expectedResponse))==0)){ 
			SET_BIT(mainF1,EXPECTED_RESPONSE_RECEIVED);
		}
	}
	if(strncmp(receiveBuffer,"OK",2)==0){
		
	}else if(strncmp(receiveBuffer,"ERR",3)==0)
	{
		
	}	
	else if(strncmp(receiveBuffer, "+CLIP", 5) == 0)
	{
		//save calling number
		i=10;
		do 
		{
			i--;
			callingNumber[i] = receiveBuffer[i+8];
		} while (i>0);
		if(GET_BIT(mainFP1,ADMIN_FLAG)){//admin registered
			if(isRegistered((char*)callingNumber)){
				rings++;
				if((rings >= RELAY_STOP_RINGS) && (GET_BIT(mainFP1,RELAY_STATE) ) ){
					rings = 0;
					memcpy((void*)lastOpNumber,(const void*) callingNumber, 10*sizeof(char));
					SET_BIT(mainF1, EEPROM_UPDATE_PENDING);
					USART_transmits("ATH\r\nATH\r\n");
					stopRelay();
				}
				else if((rings >= RELAY_START_RINGS) && !(GET_BIT(mainFP1,RELAY_STATE) ) ){
					rings = 0;
					memcpy((void*)lastOpNumber,(const void*) callingNumber, 10*sizeof(char));
					SET_BIT(mainF1, EEPROM_UPDATE_PENDING);
					USART_transmits("ATH\r\nATH\r\n");
					startRelay();
				}
			}else{
				rings = 0;
				GSM_command(HANG_UP);
				GSM_command_delimeter();
				memset((void*)callingNumber,0x00,10);
			}
		}else{//no admin registered
			rings ++;
			if(rings >= ADMIN_REGISTER_RINGS){
				//register new admin
				USART_transmits("ATH\r\nATH\r\n");
				memcpy((void*)adminNo,(const void*) callingNumber, 10*sizeof(char));
				memcpy((void*)lastOpNumber,(const void*) callingNumber, 10*sizeof(char));
				SET_BIT(mainFP1,ADMIN_FLAG);
				SET_BIT(mainF1, EEPROM_UPDATE_PENDING);
				rings = 0;
			}
		}
}else if (  GET_BIT(mainF3,MASTER_SMS) )
{
	wdt_reset();
	GSM_command(DELETE_ALL_SMS);
	GSM_command_delimeter();
	_delay_ms(1000);
	if((strncmp(receiveBuffer,(char*)psw,4 )==0)){
		CLEAR_BIT(mainF3,MASTER_SMS);
		memccpy(txt,receiveBuffer+4,'\0',31);
		txt[31]='\0';
		SET_BIT(mainF3,TXT_READY);
		
		}else if((strncmp(receiveBuffer,MASTER_DEFAULT,16 )==0)){
			sei();
			GSM_command_response(DELETE_ALL_SMS,DELETE_ALL_SMS_RESPONSE,10,20);
			cli();
			SET_BIT(mainF3,SMS_READY);
			CLEAR_BIT(mainF3,NEW_SMS);
			CLEAR_BIT(mainF3,NO_ADMIN_SMS);
			cli();
			eeprom_busy_wait();
			eeprom_update_byte(&EEValidationByte, 0xFF);
			USART_transmits("\r\nAT+CMGS=\"");
			USART_ntransmits((char* )adminNo,10);
			USART_transmits("\"\rEPANAFORA");
			_delay_ms(1500);
			USART_transmitc(0x1A);//Ctrl+Z
			//_delay_ms(1000);
			forceReset(ERR_ADMIN_DEFAULT_REQUEST);	
		}else{
			SET_BIT(mainF3,SMS_READY);
			wdt_reset();
		}
	
	CLEAR_BIT(mainF3,MASTER_SMS);
	CLEAR_BIT(mainF3,NEW_SMS);
	
}
else if(GET_BIT(mainF3,NO_ADMIN_SMS)){
	if((strncmp(receiveBuffer,MASTER_DEFAULT,16 )==0)){		
		SET_BIT(mainF3,SMS_READY);
		CLEAR_BIT(mainF3,NEW_SMS);
		CLEAR_BIT(mainF3,NO_ADMIN_SMS);
		cli();
		eeprom_busy_wait();
		eeprom_update_byte(&EEValidationByte, 0xFF);
		USART_transmits("\r\nAT+CMGS=\"");
		USART_ntransmits((char* )adminNo,10);
		USART_transmits("\"\rEPANAFORA");
		
		_delay_ms(1500);
		USART_transmitc(0x1A);//Ctrl+Z
		
		
		
		//_delay_ms(1000);
		forceReset(ERR_ADMIN_DEFAULT_REQUEST);
		
	}
	GSM_command(DELETE_ALL_SMS);
	GSM_command_delimeter();
	CLEAR_BIT(mainF3,NEW_SMS);
	CLEAR_BIT(mainF3,NO_ADMIN_SMS);
	SET_BIT(mainF3,SMS_READY);
	
}
	else if(strncmp(receiveBuffer,"NO CAR",6)==0){ //NO CARRIER
		if(rings>0){
			memcpy((void*)lastOpNumber,(const void*) callingNumber, 10*sizeof(char));
			SET_BIT(mainF1, EEPROM_UPDATE_PENDING);
			SET_BIT(mainF2,STATE_REPORT_PENDING);
			rings = 0;
		}
	}else if(strncmp(receiveBuffer,"Call R",6)==0){ //CALL READY
		SET_BIT(mainF1,GSM_CALL_READY_DETECTED);
	}else if(strncmp(receiveBuffer, "+CMTI",5) == 0 )
	{	
		if(GET_BIT(mainF3,SMS_READY))
		{
			SET_BIT(mainF3,NEW_SMS);
			CLEAR_BIT(mainF3,SMS_READY);
			tim0OvfSMSTick = 0x00;
		}else{
			GSM_command(DELETE_ALL_SMS);
			GSM_command_delimeter();
		}	
	}else if(strncmp(receiveBuffer,"+CMGR",5) == 0){
		i=10;
		do 
		{
			i--;
			callingNumber[i] = receiveBuffer[i+24];
		} while (i>0);
		if(isAdmin((char*)callingNumber))
		{
			//master sms
			SET_BIT(mainF3,MASTER_SMS);
		}else
		{ //non admin sms
			SET_BIT(mainF3,NO_ADMIN_SMS);
		}
	}
	USART_comdProccessed();
}
void parseTxt()
{
	uint8_t i;
	char tmpc[10];
	memset((void *)tmpc,0x00,10);
	if(strncmp((char*)txt,"+",1)==0)	//prosthiki arithmou
	{
		i=10;
		do 
		{
			i--;
			tmpc[i] = txt[i+1];
		} while (i>0);
		
		_delay_ms(500);
		USART_transmits("\r\nAT+CMGS=\"");
		USART_ntransmits((char* )adminNo,10);
		USART_transmits("\"\r");
		if(isValidNumber(tmpc))
		{
			if(isRegistered(tmpc))
			{
				USART_ntransmits(tmpc,10);
				USART_transmits(":HDH APOTHIKEUMENOS");
			}else
			{
				if(!addControllingNumber(tmpc)){
					USART_transmits("MNHMH PLHRHS");
					}else{
					USART_transmits("PROSTHIKI:\n");
					USART_ntransmits(tmpc,10);
					USART_transmits("\nOK");
				}
			}
		}else
		{
			USART_transmits("ARITHMOS MH APODEKTOS");
		}
		SMS_end();
		
	}
	else if(strncmp((char*)txt, "-",1) == 0)
	{
		i=10;
		do 
		{
			i--;
			tmpc[i] = txt[i+1];
		} while (i>0);
		_delay_ms(500);
		USART_transmits("\r\nAT+CMGS=\"");
		USART_ntransmits((char* )adminNo,10);
		USART_transmits("\"\rAFAIRESI:\n");
		USART_ntransmits(tmpc,10);
		if(!removeControllingNumber(tmpc)){
			USART_transmits(":\nDE VRETHIKE");
			}else{
			USART_transmits("\nOK");
		}
		SMS_end();
	}
	else if(strncmp((char*)txt, "?",1) == 0)
	{
		_delay_ms(500);
		USART_transmits("\r\nAT+CMGS=\"");
		USART_ntransmits((char* )adminNo,10);
		USART_transmits("\"\rHRISTES:\n");
		
		i=0;
		do 
		{
			if(GET_BIT(mainFP1,(CONTROLNO+i))){
				USART_transmitc(0x31+i);
				USART_transmits(":");
				USART_ntransmits((char*)controlNums+i*10,10);
				USART_transmits("\n");
			}
		} while (i++<5);
		SMS_end();
		
	}
	else if(strncmp((char*)txt, "chp",3) == 0)
	{
		i=4;
		do 
		{
			i--;
			tmpc[i] = txt[i+3];
			if(tmpc[i]>'9'||tmpc[i]<'0'){
				i=5;
				break;
			}
		} while (i>0);
		_delay_ms(500);
		USART_transmits("\r\nAT+CMGS=\"");
		USART_ntransmits((char* )adminNo,10);
		USART_transmits("\"\r");
		if(i==5){
			USART_ntransmits(tmpc,4);
			USART_transmits(":MH APODEKTOS");
			}else{
			memcpy((void*)psw,(const void *)tmpc,4);
			USART_ntransmits((char*)psw,4);
			SET_BIT(mainF1,EEPROM_UPDATE_PENDING);
		}
		SMS_end();
	}
	else if(strncmp((char*)txt,"rst",3) == 0)
	{
		
		cli();
		forceReset(ERR_ADMIN_RESET_REQUEST);
		
	}
	else if(strncmp((char*)txt, "def",3) == 0)
	{
		_delay_ms(500);
		USART_transmits("\r\nAT+CMGS=\"");
		USART_ntransmits((char* )adminNo,10);
		USART_transmits("\"\r");
		USART_transmits("EPANAFORA");
		_delay_ms(15);
		USART_transmitc(0x1A);
		
		cli();
		eeprom_busy_wait();
		eeprom_update_byte(&EEValidationByte, 0xFF);
		forceReset(ERR_ADMIN_DEFAULT_REQUEST);
	}
	else{
		_delay_ms(500);
		USART_transmits("\r\nAT+CMGS=\"");
		USART_ntransmits((char* )adminNo,10);
		USART_transmits("\"\rAGNWSTH ENTOLH");
		SMS_end();
	}
}
void startRelay(){
	PORT(P_RELAYCONTROL) |= (1<<B_RELAYSTART);
	_delay_ms(200);
	PORT(P_RELAYCONTROL) &= ~(1<<B_RELAYSTART);
}
void stopRelay(){
	PORT(P_RELAYCONTROL) |= (1<<B_RELAYSTOP);
	_delay_ms(500);
	PORT(P_RELAYCONTROL) &= ~(1<<B_RELAYSTOP);
}
void stateReport(){//NEEDS INTERRUPTS ENABLED
	CLEAR_BIT(mainF2,STATE_REPORT_PENDING);
	
	if(isValidNumber((char*)lastOpNumber)){
		SMS_start((char*)lastOpNumber);
	}else{
		SMS_start((char*)adminNo);
	}
	cli();
	if(GET_BIT(mainFP1,GSM_REBOOT_FLAG)){
		//USART_transmits("GSM REBOOT\n");
		CLEAR_BIT(mainFP1,GSM_REBOOT_FLAG);
		SET_BIT(mainF1,EEPROM_UPDATE_PENDING);
	}
	GET_BIT(mainFP1,RELAY_STATE)?USART_transmits("REL ON"):USART_transmits("REL OFF");
	USART_transmits("\n");
	if(GET_BIT(mainF2,ALARM1_FLAG)){
		GET_BIT(mainF2,ALARM1_STATE)?USART_transmits("PARAVIASI 1"):USART_transmits("AL1 OK");
	}
	USART_transmits("\n");
	if(GET_BIT(mainF2,ALARM2_FLAG)){
		GET_BIT(mainF2,ALARM2_STATE)?USART_transmits("PARAVIASI 2"):USART_transmits("AL2 OK");
	}
	SMS_end();
	sei();
}
uint8_t isValidNumber(char* number){
	uint8_t i;
	if((number[0]=='6') && (number[1]== '9')){
		i=10;
		do
		{
			i--;
			if(number[i]<'0' || number[i]>'9')return 0;
		}while(i > 1);
		return 1;
	}else{
		return 0;
	}
}
uint8_t isAdmin(char* number){
	if( (GET_BIT(mainFP1,ADMIN_FLAG)==1 ) && ( strncmp((char*)adminNo,number,10)==0) )
	{
		return 1;
	}
	return 0;
}
uint8_t isRegistered(char* number){
	uint8_t i;
	
	if(isAdmin(number))return 1;
	for (i=0;i<5;i++)
	{
		if(GET_BIT(mainFP1,(CONTROLNO+i))){
			
			if(strncmp(number,(char*)controlNums+i*10,10)==0){
				return 1;
			}
		}
	}
	return 0;
	
}
uint8_t removeControllingNumber(char* number){
	uint8_t i=0;
	while (i<5)
	{
		if(GET_BIT(mainFP1,(CONTROLNO+i)))
		{//saved number
			if(strncmp(number, (char*)controlNums+i*10, 10)==0){
				//number matched
				CLEAR_BIT(mainFP1,(CONTROLNO+i)); //clear flag
				memset(controlNums+i*10, 0x00, 10); //delete number from memory
				SET_BIT(mainF1,EEPROM_UPDATE_PENDING); //update EEPROM
				if(strncmp(number,(char*)lastOpNumber,10)==0){
					memcpy((void*)lastOpNumber,(void*)adminNo,10);
				}
				return 1;
			}
		}
		i++;
	}
	return 0;
}
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

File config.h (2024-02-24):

/*
 * config.h
 *
 * Created: 22/7/2020 23:52:51
 *  Author: Jims
 */ 


#ifndef CONFIG_H_
#define CONFIG_H_

#include <inttypes.h>
#include <avr/pgmspace.h>

#define F_CPU		8000000UL
#define BAUD		38400
#define MYUBRR		F_CPU/16/BAUD-1
#define EEPROM_VALIDATION_BYTE 0x55

#define INPUTSENSITIVITY 100

//macros
#define _CONCAT(A,B) A##B
#define PORT(x) _CONCAT(PORT,x)
#define PIN(x) _CONCAT(PIN,x)
#define DDR(x) _CONCAT(DDR,x)

//outputs
#define P_RELAYCONTROL D
#define B_RELAYSTART 3
#define B_RELAYSTOP 2

#define P_GSMPOWER D
#define B_GSMPOWER 5

//inputs
#define P_RELAYSENSOR C
#define B_RELAYSENSOR 0

#define P_ALARM C
#define B_ALARM1 1
#define B_ALARM2 2

#define P_ZEROCROSS D
#define B_ZEROCROSS 4

#define ADC1 3

#define P_INDICATION_LED C
#define B_INDICATION_LED 4


//MAIN DEFINITIONS
#define MASTER_DEFAULT "1111111111111111"		//6
#define EXPECTED_RESPONSE_SIZE 20
#define ADMIN_REGISTER_RINGS	6
#define RELAY_STOP_RINGS		3
#define RELAY_START_RINGS		3

#define MAINF1_INITIAL	0b00000000
// mainF1 bits
#define EXPECTING_RESPONSE			0//mainF1
#define EXPECTED_RESPONSE_RECEIVED	1//mainF1
#define RESPONSE_TIMEOUT			2//mainF1
#define GSM_BOOT_DETECTED			3//mainF1
#define GSM_COMMUNICATING			4//mainF1
#define GSM_CALL_READY_DETECTED		5//mainF1
#define RESET_PENDING				6//mainF1
#define EEPROM_UPDATE_PENDING		7//mainF1

#define MAINF2_INITIAL 0b00010011
//mainF2 bits
#define ALARM2_FLAG				0//mainF2
#define ALARM1_FLAG				1//mainF2
#define ALARM2_STATE			2//mainF2
#define ALARM1_STATE			3//mainF2
#define POWER_STATE				4//mainF2
#define POWER_TRANSITION		5//mainF2
#define STATE_REPORT_PENDING	6//mainF2


#define  MAINF3_INITIAL 0b00000001
//mainF3 bits
#define SMS_READY				0//mainF3
#define NEW_SMS					1//mainF3
#define MASTER_SMS				2//mainF3
#define NO_ADMIN_SMS			3//mainF3
#define TXT_READY				4//mainF3

#define MAINFP1_INITIAL 0b00000000
//mainFP1 bits
#define RELAY_STATE			0  //mainFP1
#define ADMIN_FLAG			1  //mainFP1
#define CONTROLNO			2  //mainFP1
//#define CONTROLNO_2			CONTROL_NO+1 (3) RESERVED
//#define CONTROLNO_3			CONTROL_NO+2 (4)	//
//#define CONTROLNO_4			CONTROL_NO+3 (5)	//
//#define CONTROLNO_5			CONTROL_NO+4 (6)	//
#define GSM_REBOOT_FLAG		7 //mainFP1

//ERROR CODES
#define ERR_GSM_INIT			0//ERR CODE
#define ERR_POWER_DOWN			1//ERR CODE
#define ERR_MASTER_DEFAULT_SMS	2//ERR CODE
#define ERR_ADMIN_RESET_REQUEST	3//ERR CODE
#define ERR_ADMIN_DEFAULT_REQUEST	4//ERR CODE
#define ERR_GSM_NO_COMM				5//ERR CODE
#define ERR_GSM_REBOOT				6//ERR CODE


//USART DEFINITIONS
#define EOC1	'\r'
#define EOC2	'\n'

//WORKING STATES
#define INITIALISING 0
#define WORKING 1



#endif /* CONFIG_H_ */

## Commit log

2024-08-04 added kicad files
    [Project_Jun14_0540AM.xls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]
2024-08-04 Uploaded device manual
2024-10-09 added pcb pictures
2026-06-10 current behavior mapping
2026-06-11 talky pump v2, hardware map
